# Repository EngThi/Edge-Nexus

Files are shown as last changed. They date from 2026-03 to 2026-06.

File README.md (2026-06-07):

# Edge Nexus: Standalone Industrial Edge Controller

This is a custom industrial carrier board I built for high-noise environments. It uses PC817 optocouplers for isolation and has RS-485/Modbus comms through an SP3485 chip. I managed to get the hardware under $50 by sourcing directly from LCSC and AliExpress.

## Why I built this

Edge Nexus is an industrial controller meant to bridge the gap between standard IoT boards and noisy factory floors. It started as a shield for bigger SBCs, but I decided to make it standalone. It focuses on actual hardware engineering rather than just plugging things into a Linux computer.

I'm a Computer Engineering student and I wanted a solid, protected brain for automation and logging that doesn't cost a fortune like those industrial PLCs you see out there.

## On the board

- ESP32-S3 (WeAct Studio module). It handles the logic, WiFi, and Bluetooth.
- 4-channel input protection using PC817 optocouplers. This stops high-voltage spikes from killing the ESP32.
- SP3485 transceiver for RS-485 / Modbus. This is the standard for industrial PLCs.
- Built-in LM2596 buck converter. You can power the whole thing from a 12-19V laptop brick.
- Two 5V relays to switch actual loads.
- INA219 for power monitoring, SHT41 for temp/humidity, and a DS3231 RTC for keeping time offline.
- MicroSD slot to save logs without needing a cloud connection.
- 40-pin expansion/service header kept for debugging, future wiring, and compatibility experiments.
- Front HMI board with WS2812B status LEDs and a tactile button.

## Design and Making it

### PCB Layout
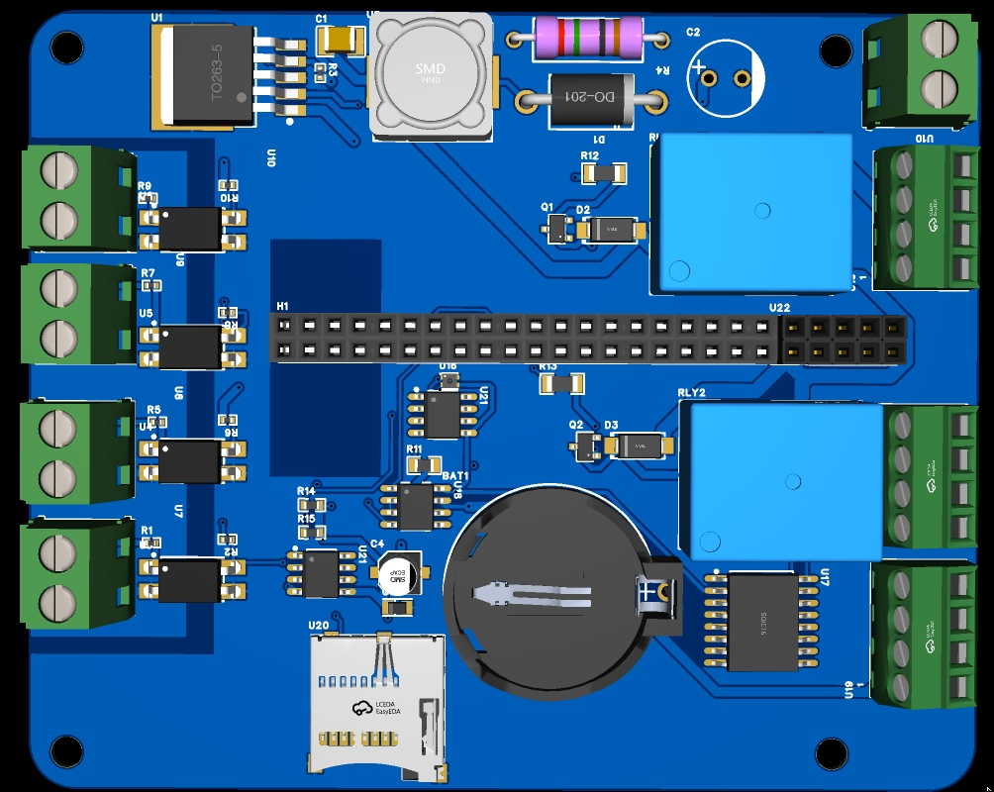
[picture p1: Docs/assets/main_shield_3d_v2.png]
PCB View

*V2 Standalone Controller and the routing details.*

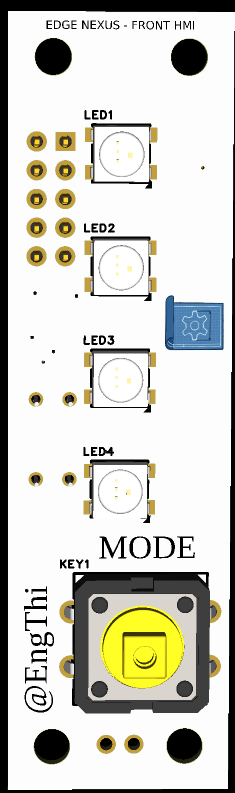
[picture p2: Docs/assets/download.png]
Front HMI View


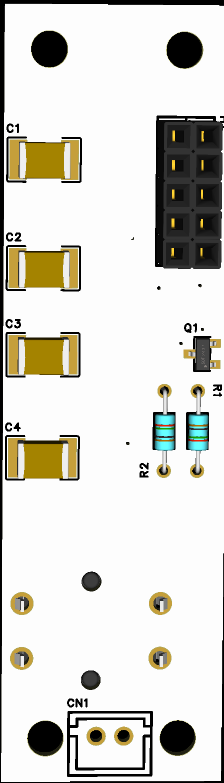
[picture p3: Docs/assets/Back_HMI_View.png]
Back HMI View


### Mechanicals
I designed the enclosure in OnShape with mounting bosses and enough space for the relays and the ESP32.
- [OnShape Public Link](https://cad.onshape.com/documents/763a97ddcd49a121183cadac/w/b6354cba14e3b3f32c74d1b6/e/a910c6222f3a54e8127254ee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)

## How to use it

### Power

The board runs on 12 to 19V DC via a barrel jack. Those small power bricks
that come with set-top boxes and older electronics (the kind everyone has
lying around here in Brazil, usually 12V P4) work fine. Laptop chargers
cover the 19V end. If it outputs somewhere in that range and the connector
fits, it probably works :)

One thing worth knowing: I originally designed this thinking about a
Jetson Nano doing the heavy lifting, model finetuning, industrial
simulations, the kind of workload that needs real compute. After the pivot
to ESP32-S3 that changed. The ESP handles control logic, comms, and
logging really well but it is not going to run ML workloads :/. The 40-pin
header stayed in as an expansion connector if you ever want to attach
something more powerful later.

### DIRTY side vs CLEAN side

The left side of the board is the DIRTY side, that is where your sensors,
actuators, and anything with messy real-world signals connect via screw
terminals. Those signals never touch the ESP directly. The PC817
optocouplers convert them to light pulses and pass only the logic signal
across the isolation barrier to the CLEAN side where the ESP lives. So if
something on the DIRTY side has a spike or does something weird, the ESP
does not care :p

### Flashing the ESP32-S3

I went with MicroPython because iteration is faster, write a `.py`,
upload, test, repeat. But the ESP32-S3 works with C/C++ and even Rust if
you prefer.

**MicroPython:**
Grab the binary for the S3 from the
[official MicroPython page](https://micropython.org/download/ESP32_GENERIC_S3/).
Best IDE for this is Thonny, pick the version, connect the board, select
the COM port and flash the `.bin`. To enter flash mode hold BOOT, tap
EN/RST then release BOOT. Wait for it to finish and you are good :). After
that you write and test `.py` files straight from Thonny's console.

**C/C++ via Arduino IDE, PlatformIO, or ESP-IDF:**
Pick your board (ESP32-S3), pick the COM port, compile and flash. Most of
the time you do not even need to hold BOOT, the toolchain handles it. If
the flash fails or the bar just hangs, hold BOOT when it starts uploading
and release once it moves. That usually fixes it :/

### RS-485 and Modbus

The SP3485 transceiver gives you RS-485, same physical layer most
industrial PLCs use. Modbus RTU runs on top of that so you can talk to
PLCs, VFDs, sensors, basically anything on a factory floor that has a
Modbus register map. Two wires (A and B), twisted pair, multiple devices
on the same bus. The firmware handles DE/RE pin direction switching
automatically so you do not have to manage that manually.

### SD card logging

There is a MicroSD slot that saves telemetry to a simple `.csv`, temperature,
humidity, relay state, timestamps, whatever the firmware is collecting. Right
now it just keeps appending rows to one file :/

Still on the list: better file rotation, separate files per task, checking
card health on boot instead of just assuming it is there. Also been thinking
about pushing data to a cloud dashboard via webhooks, something like
[Blynk](https://www.blynk.io/) which I used in my TCC (that is kind of like
a Capstone Project or Undergraduate Thesis, from my Industrial Automation
technician course here in Brazil). WiFi is already there on the ESP, just
have not wired that part up yet :)

## How I'm assembling it

The PCB is coming bare from JLCPCB. I'm hand-soldering everything myself—optoacopladores, the transceiver, buck converter, and all the headers. I want to verify the isolation gap and continuity manually before I ever turn it on.

## Cost to replicate

This is the price for the parts, not including shipping or taxes.

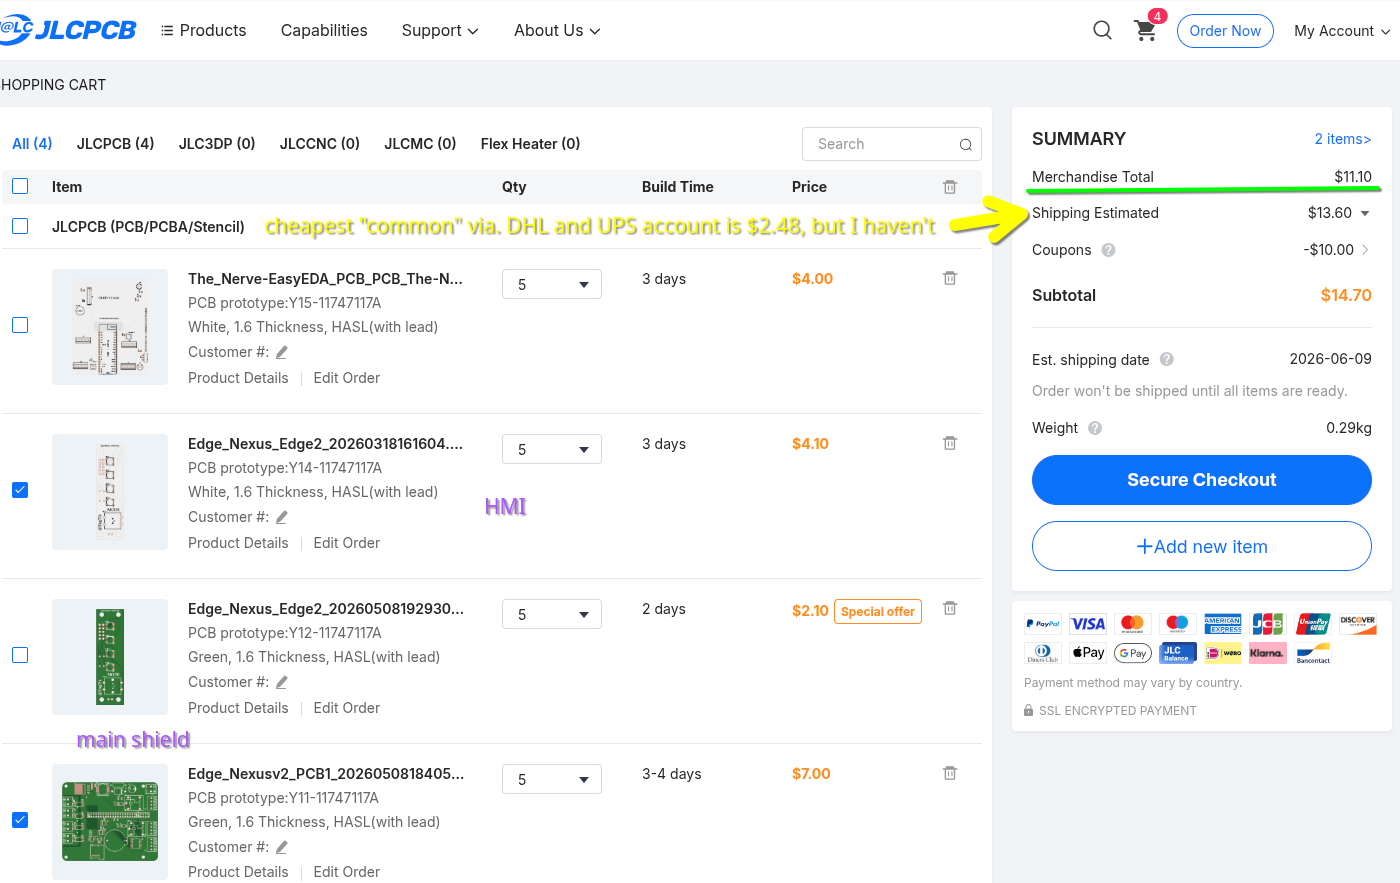
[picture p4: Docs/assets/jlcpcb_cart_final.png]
Final JLCPCB Cart

*Selected JLCPCB PCBs: shield + HMI with logo/sign.*

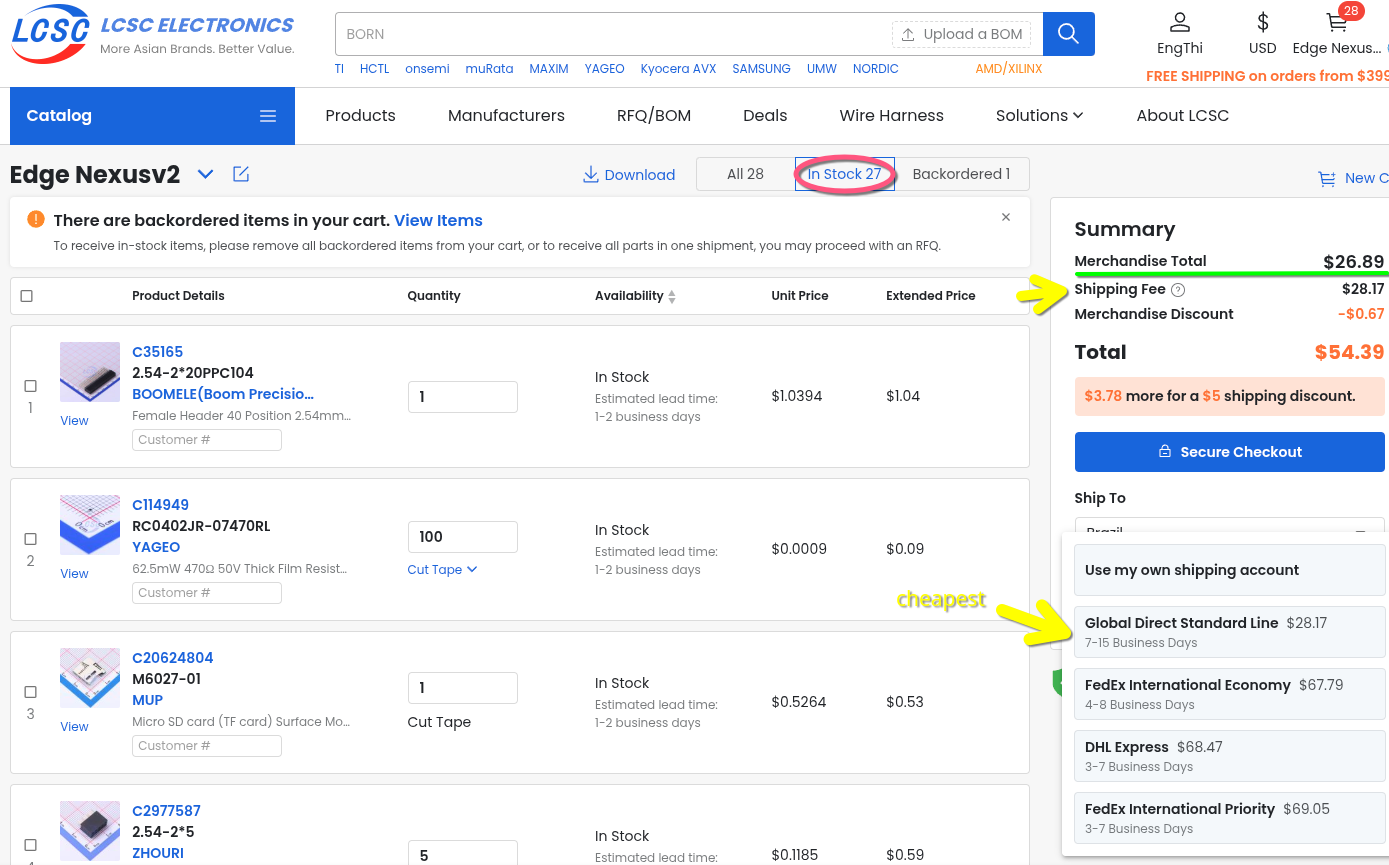
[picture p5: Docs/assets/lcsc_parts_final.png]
Main Shield LCSC Cart

*Main Shield parts from LCSC. This is the cart I submitted with the project.*

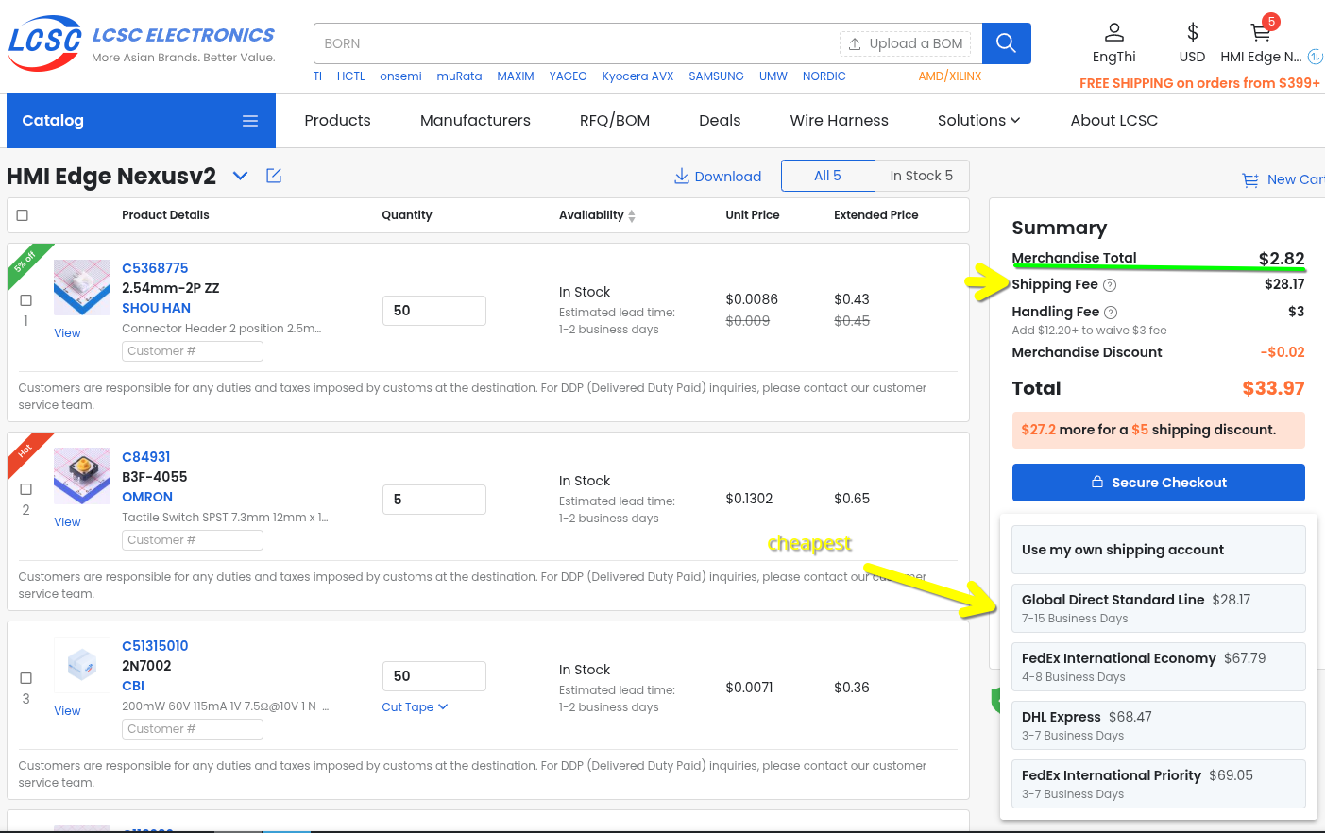
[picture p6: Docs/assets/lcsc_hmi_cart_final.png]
Front HMI LCSC Cart

*Front HMI parts from LCSC.*

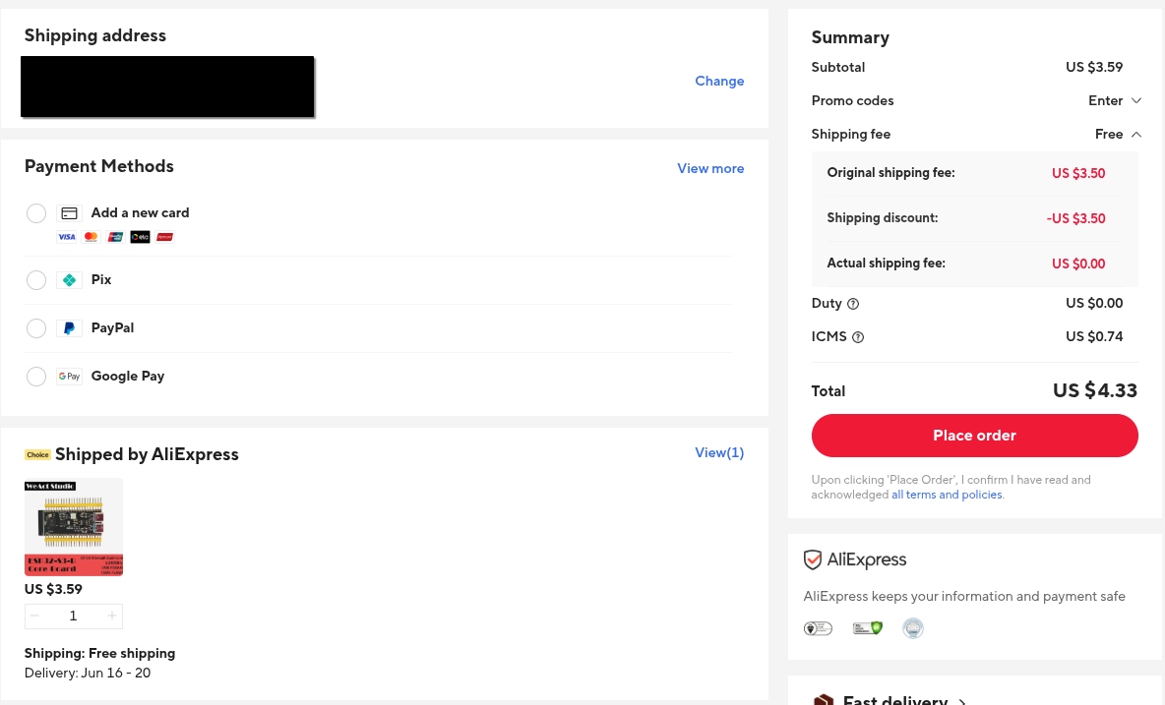
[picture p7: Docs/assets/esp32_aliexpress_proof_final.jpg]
AliExpress Proof

*ESP32-S3 from AliExpress.*

| Item | Qty | From | Price |
| :--- | :--- | :--- | :--- |
| ESP32-S3 WeAct Studio | 1 | AliExpress | $4.33 |
| Main Shield components cart | 1 set | LCSC | $26.89 |
| Front HMI components cart | 1 set | LCSC | $2.82 |
| PCB Manufacturing (Shield + HMI) | 1 set | JLCPCB | $11.10 |
| **Subtotal (Hardware Only)** | | | **$45.14** |

> **Note on cost optimization:** After submitting the form, I noticed that
> combining both LCSC carts into one order drops the total merchandise to
> $29.71 and cuts shipping to a single $28.17 charge instead of two.
> Here's what that looks like:
>
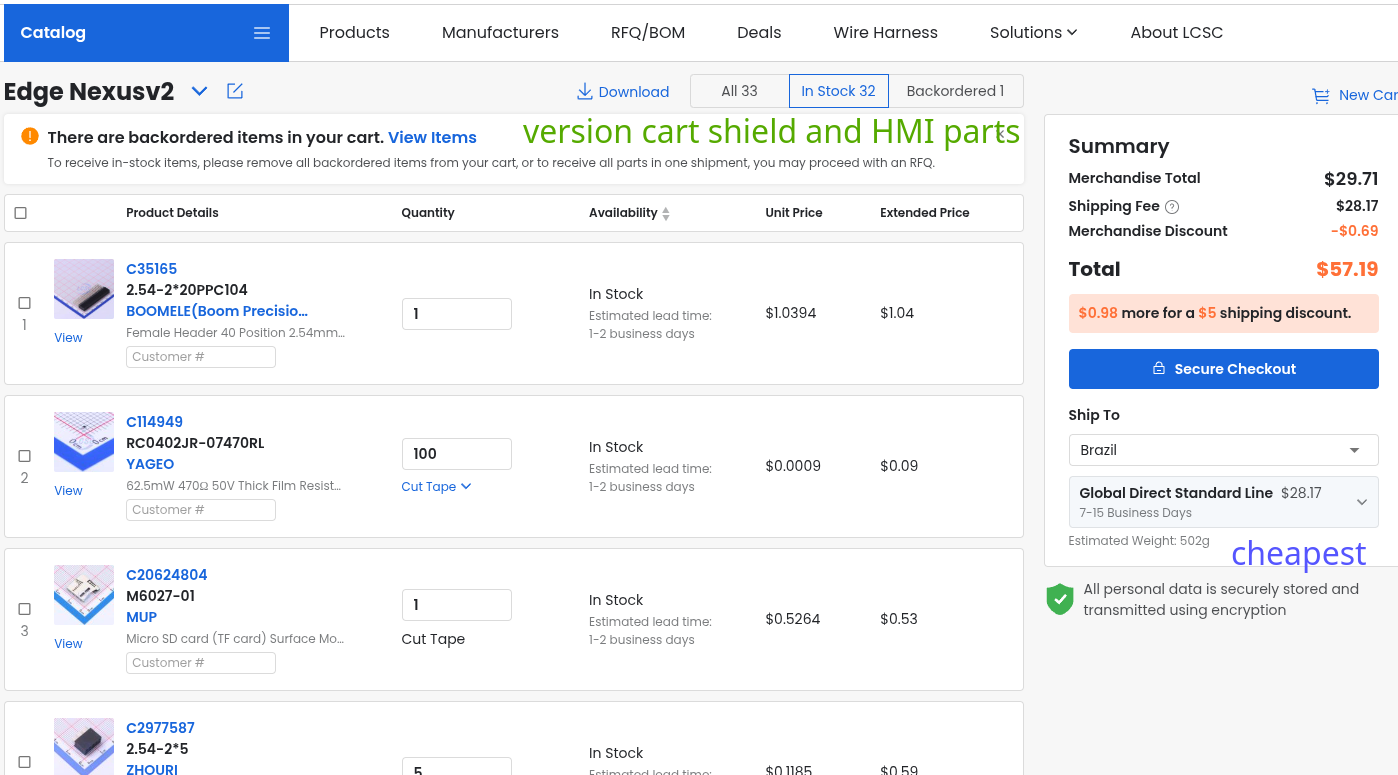
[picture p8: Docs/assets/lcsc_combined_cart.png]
Combined LCSC Cart
> 
> *Shield + HMI parts in one cart — $29.71 merchandise, one shipping charge.*

*(Full details with shipping and taxes in [BLUEPRINT_BUDGET.md](BLUEPRINT_BUDGET.md))*

That total is the real merchandise/cart number before shipping and taxes. It is not a perfect "one resistor costs this much" calculation, because LCSC has MOQ and stock weirdness. Still, it is the number I would rather show because it is what I actually see in the carts.

Note for people in Brazil (São Paulo): If you are around Santa Ifigênia, you can get most of the passives and connectors there for cheap. The ESP32 and LCSC orders usually stay under the tax limit if you're careful.

Check BOM.csv

### Shipping info
I used Global Standard Direct Line for the PCBs, which is the cheapest tracked option to Brazil.

## Folder Structure

```
├── BOM.csv                         # Full parts list
├── JOURNAL.md                      # Engineering logs
├── Hardware/
│   ├── Main_Shield/
│   │   ├── Fabrication/            # Gerbers and BOM
│   │   ├── PCB/                    # EasyEDA files
│   │   └── Schematics/             # PDF Schematic
│   ├── Front_HMI/                  # HMI board files
│   └── 3D_Models/                  # STEP files
├── Docs/                           # Images and renders
└── software/
    └── main.py                     # Firmware
```

---

Developed for Hack Club Blueprint 2026. Designed by @EngThi

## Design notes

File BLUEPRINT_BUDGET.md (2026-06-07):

# Edge Nexus Hardware Budget

This document outlines the hardware costs for Edge Nexus. The budget is split into **Component Base Prices** (the actual cost of the parts) and **Shipping & Taxes** (the fees to get them to Brazil).

## 1. Component Base Prices (Hardware Only)

| Part | Supplier | Price (USD) |
| :--- | :--- | :--- |
| ESP32-S3 WeAct Studio module | AliExpress | $4.33 |
| Main Shield components cart | LCSC | $26.89 |
| Front HMI components cart | LCSC | $2.82 |
| Edge Nexus V2 PCB order (Shield + HMI) | JLCPCB | $11.10 |
| **Subtotal Components** | | **$45.14** |

---

## 2. Shipping & Regional Taxes (Estimated)

| Supplier / Fee Type | Cost (USD) |
| :--- | :--- |
| JLCPCB Shipping | $13.05 |
| LCSC Shipping (Global Direct) | $31.17 |
| AliExpress Taxes (ICMS) | $0.00 (Included in part price) |
| **Subtotal Shipping & Taxes** | **$44.22** |

---

## 3. Final Total

| Total Project Cost | $45.14 (Parts) + $44.22 (Shipping/Taxes) | **$89.36** |
| :--- | :--- | :--- |

## Proof of Costs (Final Carts)
- [AliExpress ESP32 Proof](Docs/assets/esp32_aliexpress_proof_final.jpg)
- [JLCPCB Final Cart](Docs/assets/jlcpcb_cart_final.png)
- [LCSC Main Shield Cart](Docs/assets/lcsc_parts_final.png)
- [LCSC Front HMI Cart](Docs/assets/lcsc_hmi_cart_final.png)
- [LCSC Optimized/Combined Cart](Docs/assets/lcsc_combined_cart.png)

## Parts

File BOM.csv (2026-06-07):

Category | Quantity | Component | Designator | Manufacturer | Part Number | Supplier | Unit Price (USD) | MOQ | Link
Computing | 1 | ESP32-S3 WeAct Studio | U1 | WeAct Studio | ESP32-S3-N16R8 | AliExpress | 4.33 | 1 | https://pt.aliexpress.com/item/1005005592730189.html
Comms | 1 | SP3485 RS-485 Transceiver | U18 | MaxLinear | C8963 | LCSC | 0.45 | 1 | https://www.lcsc.com/product-detail/RS-485-RS-422-Receivers-Transceivers_MaxLinear-Exar-SP3485EN-L-TR_C6767.html
Power | 1 | LM2596S-ADJ Buck Converter | U1 | UMW | C347423 | LCSC | 0.57 | 1 | https://www.lcsc.com/product-detail/DC-DC-Converters_UMW-友台半导体-LM2596S-ADJ-UMW_C347423.html
Isolation | 4 | PC817C Optocoupler | U3-U6 | GOODWORK | C3025164 | LCSC | 0.04 | 20 | https://www.lcsc.com/product-detail/Optoisolators-Transistor-Photovoltaic-Output_GOODWORK-PC817C_C3025164.html
Actuation | 2 | 5V Relay (SRD-05VDC-SL-C) | RLY1-RLY2 | Songle | C35449 | LCSC | 0.42 | 1 | https://www.lcsc.com/product-detail/Relays_Songle-Relay-SRD-05VDC-SL-C_C35449.html
Sensors | 2 | INA219 Current Sensor | U21 | TI | C138706 | LCSC | 0.85 | 1 | https://www.lcsc.com/product-detail/Current-Sensors_Texas-Instruments-INA219AIDR_C138706.html
Sensors | 1 | SHT41A Temp/Hum Sensor | U16 | Sensirion | C7461859 | LCSC | 1.50 | 1 | https://www.lcsc.com/product-detail/Temperature-Humidity-Sensors_Sensirion-AG-SHT41A-BD1B-R2_C7461859.html
Clock | 1 | DS3231 RTC | U17 | Maxim | C722469 | LCSC | 1.20 | 1 | https://www.lcsc.com/product-detail/Real-Time-Clocks-RTC_Maxim-Integrated-DS3231SN_C722469.html
Storage | 1 | MicroSD Slot (SPI) | U20 | MUP | C20624804 | LCSC | 0.15 | 1 | https://www.lcsc.com/product-detail/SD-Card-Connectors_MUP-M6027-01_C20624804.html
Discrete | 2 | S8050 NPN Transistor | Q1-Q2 | CJ | C2146 | LCSC | 0.01 | 50 | https://www.lcsc.com/product-detail/Bipolar-Transistors-BJT_CJ-S8050_C2146.html
Discrete | 1 | 1N5822 Schottky Diode | D1 | LRC | C82806 | LCSC | 0.15 | 5 | https://www.lcsc.com/product-detail/Schottky-Diodes_LRC-1N5822_C82806.html
Discrete | 2 | 1N4007 Diode | D2-D3 | Generic | C727081 | LCSC | 0.02 | 100 | https://www.lcsc.com/product-detail/Diodes-General-Purpose_YONGYUTAI-1N4007_C727081.html
Passives | 1 | 100uH Inductor | U2 | SHOU HAN | C2929505 | LCSC | 0.38 | 5 | https://www.lcsc.com/product-detail/Inductors-SMD_SHOU-HAN-CYH127-100UH_C2929505.html
Passives | 1 | 220uF Capacitor | C1 | SAMSUNG | C400951 | LCSC | 0.91 | 1 | https://www.lcsc.com/product-detail/Multilayer-Ceramic-Capacitors-MLCC-SMD-SMT_SAMSUNG-CL32A227MQVNNNE_C400951.html
Passives | 1 | 100uF Capacitor (35V) | C2 | Econd | C49304899 | LCSC | 0.10 | 10 | https://www.lcsc.com/product-detail/Electrolytic-Capacitors-Leaded_Econd-100uF35V8x11GF_C49304899.html
Passives | 1 | 10uF Capacitor | C3 | CEC | C2976905 | LCSC | 0.05 | 10 | https://www.lcsc.com/product-detail/Tantalum-Capacitors_CEC-CA45A-P-6-3V-10UF-K_C2976905.html
Passives | 1 | 100nF Capacitor | C4 | HUAWEI | C271438 | LCSC | 0.02 | 100 | https://www.lcsc.com/product-detail/Aluminum-Electrolytic-Capacitors-SMD_HUAWEI-VT1H0R1MB054000CE0_C271438.html
Passives | 4 | 470Ω Resistor 0402 | R1,R5,R7,R9 | YAGEO | C114949 | LCSC | 0.001 | 100 | https://www.lcsc.com/product-detail/Chip-Resistor-Surface-Mount_YAGEO-RC0402JR-07470RL_C114949.html
Passives | 5 | 10kΩ Resistor 0402 | R2,R3,R6,R8,R10 | EVER OHMS | C149898 | LCSC | 0.02 | 50 | https://www.lcsc.com/product-detail/Chip-Resistor-Surface-Mount_EVER-OHMS-TR0402D10K0Q1025Z_C149898.html
Passives | 2 | 4.7kΩ Resistor 0603 | R14-R15 | UNI-ROYAL | C23162 | LCSC | 0.01 | 100 | https://www.lcsc.com/product-detail/Chip-Resistor-Surface-Mount_UNI-ROYAL-0603WAF4701T5E_C23162.html
Passives | 2 | 1kΩ Resistor 1206 | R12-R13 | UNI-ROYAL | C4410 | LCSC | 0.01 | 100 | https://www.lcsc.com/product-detail/Chip-Resistor-Surface-Mount_UNI-ROYAL-1206W4F1001T5E_C4410.html
Passives | 1 | 120Ω Resistor 0805 | R11 | Generic | C384167 | LCSC | 0.01 | 100 | https://www.lcsc.com/product-detail/Chip-Resistor-Surface-Mount_UNI-ROYAL-WR08X121JTL_C384167.html
Passives | 1 | 3.3kΩ Resistor TH | R4 | Huaxing | C714109 | LCSC | 0.03 | 20 | https://www.lcsc.com/product-detail/Through-Hole-Resistors_华星机电-MF1W-3.3K-1-T_C714109.html
Connectors | 1 | 40-pin Female Header (PC104) | H1 | BOOMELE | C35165 | LCSC | 1.03 | 1 | https://www.lcsc.com/product-detail/Female-Headers_BOOMELE-C35165_C35165.html
Connectors | 1 | CR2032 Battery Holder | BAT1 | Generic | C9900018737 | LCSC | 0.25 | 1 | https://www.lcsc.com/product-detail/Battery-Holders_CR2032-2-1_C9900018737.html
Connectors | 4 | KF128-5.0-2P Screw Terminal | J2-J5 | KEFA | C474950 | LCSC | 0.18 | 5 | https://www.lcsc.com/product-detail/Screw-Terminal-Blocks_KEFA-KF128-5.0-2P_C474950.html
Connectors | 3 | 4-pin Screw Terminal (3.5mm) | U19 | MAX | C5349545 | LCSC | 0.30 | 1 | https://www.lcsc.com/product-detail/Screw-Terminal-Blocks_MAX-MX127S-3-5-04P-GN01-CU-Y-A_C5349545.html
Connectors | 1 | 2x5 pin Header | U22 | ZHOURI | C2977587 | LCSC | 0.15 | 1 | https://www.lcsc.com/product-detail/Female-Headers_ZHOURI-2-54-2-5_C2977587.html
Passives | 4 | 100nF Film Capacitor | C1-C4 | WIMA | C19855121 | LCSC | 0.136 | 1 | https://www.lcsc.com/product-detail/Film-Capacitors_WIMA-SMDTC03100KB00KP00_C19855121.html
Connectors | 1 | 2.54mm-2P ZZ Header | CN1 | SHOU HAN | C5368775 | LCSC | 0.0013 | 1 | https://www.lcsc.com/product-detail/Wire-To-Board-Connector_SHOU-HAN-2-54mm-2P-ZZ_C5368775.html
Connectors | 1 | 2x5 pin Female Header | H1 | BOOMELE | C30419 | LCSC | 0.0097 | 1 | https://www.lcsc.com/product-detail/Female-Headers_BOOMELE-HDR2-54-F-LI-2X5P_C30419.html
Switches | 1 | Tactile Switch B3F-4055 | KEY1 | OMRON | C84931 | LCSC | 0.0207 | 1 | https://www.lcsc.com/product-detail/Tactile-Switches_OMRON-B3F-4055_C84931.html
Optoelectronics | 4 | WS2812B-V5 RGB LED | LED1-LED4 | worldsemi | C2846931 | LCSC | 0.143 | 1 | https://www.lcsc.com/product-detail/RGB-LEDs-Built-in-IC_worldsemi-WS2812B-V5_C2846931.html
Discrete | 1 | 2N7002 MOSFET | Q1 | CBI | C51315010 | LCSC | 0.0011 | 1 | https://www.lcsc.com/product-detail/MOSFETs_CBI-2N7002_C51315010.html
Resistors | 2 | 10kΩ TH Resistor | R1-R2 | CCO | C119202 | LCSC | 0.0016 | 1 | https://www.lcsc.com/product-detail/Through-Hole-Resistors_CCO-MF1-8W-10K-1-T_C119202.html
PCB | 1 | Edge Nexus V2 PCB (Shield) | Main | JLCPCB | Custom | JLCPCB | 7.00 | 5 | https://jlcpcb.com
PCB | 1 | Edge Nexus Front HMI PCB (Logo/Sign) | HMI | JLCPCB | Custom | JLCPCB | 4.10 | 5 | https://jlcpcb.com

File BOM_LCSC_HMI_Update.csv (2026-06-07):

Index | LCSC# | MPN | Manufacturer | Package | Customer # | Description | RoHS | Quantity | MOQ | Multiple | Unit Price($) | Extended Price($) | Product Link
1 | C5368775 | 2.54mm-2P ZZ | SHOU HAN | Through Hole,P=2.5mm |  | Connector Header 2 position 2.5mm Pitch 3A Through Hole -25℃~+85℃ | yes | 50 | 50 | 50 | 0.0086 | 0.43 | https://www.lcsc.com/product-detail/C5368775.html
2 | C84931 | B3F-4055 | OMRON | Through Hole-4P,12x12mm |  | Tactile Switch SPST 7.3mm 12mm x 12mm Through Hole | yes | 5 | 5 | 5 | 0.1302 | 0.65 | https://www.lcsc.com/product-detail/C84931.html
3 | C51315010 | 2N7002 | CBI | SOT-23 |  | 200mW 60V 115mA 1V 7.5Ω@10V 1 N-channel N-Channel SOT-23 Single FETs, MOSFETs RoHS | yes | 50 | 50 | 50 | 0.0071 | 0.36 | https://www.lcsc.com/product-detail/C51315010.html
4 | C119202 | MF1/8W-10KΩ±1% T | CCO(Chian Chia Elec) | Through Hole,D1.8xL3.2mm |  | 10kΩ 125mW 150V Metal Film Resistor ±100ppm/℃ ±1% Through Hole,D1.8xL3.2mm Through Hole Resistors RoHS | yes | 50 | 50 | 50 | 0.0104 | 0.52 | https://www.lcsc.com/product-detail/C119202.html
5 | C49678 | CC0805KRX7R9BB104 | YAGEO | 0805 |  | 100nF ±10% 50V Ceramic Capacitor X7R 0805 | yes | 100 | 100 | 100 | 0.0084 | 0.84 | https://www.lcsc.com/product-detail/C49678.html

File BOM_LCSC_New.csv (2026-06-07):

Index | LCSC# | MPN | Manufacturer | Package | Customer # | Description | RoHS | Quantity | MOQ | Multiple | Unit Price($) | Extended Price($) | Product Link
1 | C35165 | 2.54-2*20PPC104 | BOOMELE(Boom Precision Elec) | Through Hole,P=2.54mm |  | Female Header 40 Position 2.54mm Pitch Dual Row Through Hole | yes | 1 | 1 | 1 | 1.0394 | 1.04 | https://www.lcsc.com/product-detail/C35165.html
2 | C7461859 | SHT41A-BD1B-R2 | Sensirion | - |  | - | - | 1 | 1 | 1 | 2.2096 | 2.21 | -
3 | C114949 | RC0402JR-07470RL | YAGEO | 0402 |  | 62.5mW 470Ω 50V Thick Film Resistor ±100ppm/℃ ±5% 0402 Chip Resistor - Surface Mount RoHS | yes | 100 | 100 | 100 | 0.0009 | 0.09 | https://www.lcsc.com/product-detail/C114949.html
4 | C20624804 | M6027-01 | MUP | SMD |  | Micro SD card (TF card) Surface Mount | yes | 1 | 1 | 1 | 0.5264 | 0.53 | https://www.lcsc.com/product-detail/C20624804.html
5 | C2977587 | 2.54-2*5 | ZHOURI | Through Hole,P=2.54mm |  | Female Header 10 Position 2.54mm Pitch Dual Row Through Hole -40℃~+105℃ | yes | 5 | 5 | 5 | 0.1185 | 0.59 | https://www.lcsc.com/product-detail/C2977587.html
6 | C49304899 | 100uF35V8x11GF | Econd | Through Hole,D8xL11mm |  | ±20% 35V 100uF 170mΩ Through Hole,D8xL11mm Aluminum Electrolytic Capacitors RoHS | yes | 20 | 20 | 20 | 0.0281 | 0.56 | https://www.lcsc.com/product-detail/C49304899.html
7 | C5365915 | KH-CR2032-2-1 | kinghelm | Through Hole |  | Battery base Tin Brass -55℃~+105℃ CR2032 Through Hole Blade Type Power Connector Assemblies RoHS | yes | 5 | 5 | 5 | 0.1366 | 0.68 | https://www.lcsc.com/product-detail/C5365915.html
8 | C722469 | DS3231SN# | MAXIM | SOIC-16-300mil |  | Built-in Yes SOIC-16-300mil Real Time Clocks RoHS | yes | 1 | 1 | 1 | 6.0330 | 6.03 | https://www.lcsc.com/product-detail/C722469.html
9 | C727081 | 1N4007 | TWGMC | SMA(DO-214AC) |  | Diode Independent 1kV 1A Surface Mount SMA(DO-214AC) | yes | 50 | 50 | 50 | 0.0091 | 0.46 | https://www.lcsc.com/product-detail/C727081.html
10 | C35449 | SRD-05VDC-SL-C | Songle Relay | Through Hole,19.2x15.6mm |  | Power Relay 1 Form C: 1C (SPDT-CO) 5V Coil Through Hole,15.6x19.2mm | yes | 2 | 1 | 1 | 0.4880 | 0.98 | https://www.lcsc.com/product-detail/C35449.html
11 | C163961 | WR08X121JTL | Walsin | 0805 |  | 125mW 120Ω 150V Thick Film Resistor ±100ppm/℃ ±5% 0805 Chip Resistor - Surface Mount RoHS | yes | 100 | 100 | 100 | 0.0024 | 0.24 | https://www.lcsc.com/product-detail/C163961.html
12 | C8963 | SP3485EN-L/TR | MaxLinear | SOIC-8 |  | 3.3V Transceiver 10Mbps 32 Half-Duplex SOIC-8 Drivers, Receivers, Transceivers RoHS | yes | 2 | 2 | 2 | 0.3085 | 0.62 | https://www.lcsc.com/product-detail/C8963.html
13 | C271438 | VT1H0R1MB054000CE0 | huawei group | SMD,D4xL5.4mm |  | 0.1uF ±20% 50V Aluminum Electrolytic Capacitors 1000hrs@105℃ | yes | 20 | 20 | 20 | 0.0406 | 0.81 | https://www.lcsc.com/product-detail/C271438.html
14 | C2976905 | CA45A-P-6.3V-10UF-K | XY(Zhenhua XinYun) | SMD,1.25x2mm |  | 10uF ±10% 6.3V Tantalum Capacitors SMD,1.25x2mm | yes | 5 | 5 | 5 | 0.1137 | 0.57 | https://www.lcsc.com/product-detail/C2976905.html
15 | C2146 | S8050 J3Y(RANGE:200-350) | JSCJ | SOT-23 |  | Bipolar (BJT) Transistor NPN 25V 0.5A 150MHz 0.3W Surface Mount SOT-23 | yes | 50 | 50 | 50 | 0.0133 | 0.67 | https://www.lcsc.com/product-detail/C2146.html
16 | C4410 | 1206W4F1001T5E | UNI-ROYAL | 1206 |  | 1kΩ ±1% 250mW 1206 Thick Film Resistor | yes | 100 | 100 | 100 | 0.0045 | 0.45 | https://www.lcsc.com/product-detail/C4410.html
17 | C138706 | INA219AIDR | TI | SOIC-8 |  | 0V~26V 10uV 20nA 1 SOIC-8 Current Regulation/Management RoHS | yes | 2 | 1 | 1 | 0.9815 | 1.96 | https://www.lcsc.com/product-detail/C138706.html
18 | C474950 | KF128-5.0-2P | Cixi Kefa Elec | Through Hole,P=5mm |  | 2 Position Wire to Board Terminal Block Through Hole 5mm | yes | 5 | 5 | 5 | 0.1838 | 0.92 | https://www.lcsc.com/product-detail/C474950.html
19 | C347423 | LM2596S-ADJ(UMW) | UMW | TO-263-5 |  | 150kHz Step-down type Adjustable 1.2V~37V 3A TO-263-5 Voltage Regulators - DC DC Switching Regulators RoHS | yes | 1 | 1 | 1 | 0.5504 | 0.55 | https://www.lcsc.com/product-detail/C347423.html
20 | C3025164 | PC817C | GOODWORK | SMD-4P |  | Phototransistor Output 5kVrms 1 Channel SMD-4P | yes | 20 | 20 | 20 | 0.0391 | 0.78 | https://www.lcsc.com/product-detail/C3025164.html
21 | C400951 | CL32A227MQVNNNE | Samsung Electro-Mechanics | 1210 |  | 220uF ±20% 6.3V Ceramic Capacitor X5R 1210 | yes | 1 | 1 | 1 | 1.0069 | 1.01 | https://www.lcsc.com/product-detail/C400951.html
22 | C2929505 | CYH127-100UH | SHOU HAN | SMD,12.3x12.3mm |  | 1.7A 100uH ±20% 220mΩ SMD,12.3x12.3mm Fixed Inductors RoHS | yes | 5 | 5 | 5 | 0.3858 | 1.93 | https://www.lcsc.com/product-detail/C2929505.html
23 | C149898 | TR0402D10K0Q1025Z | EVER OHMS | 0402 |  | 63mW 10kΩ 25V Thin Film Resistor ±0.5% ±25ppm/℃ 0402 Chip Resistor - Surface Mount RoHS | yes | 50 | 50 | 50 | 0.0173 | 0.87 | https://www.lcsc.com/product-detail/C149898.html
24 | C5349545 | MX127S-3.5-04P-GN01-Cu-Y-A | MAX | Through Hole,P=3.5mm |  | 4 Position Wire to Board Terminal Block Through Hole 3.5mm | yes | 3 | 1 | 1 | 0.4456 | 1.34 | https://www.lcsc.com/product-detail/C5349545.html
25 | C99782 | RC0603FR-074K7L | YAGEO | 0603 |  | 100mW 4.7kΩ 75V Thick Film Resistor ±100ppm/℃ ±1% 0603 Chip Resistor - Surface Mount RoHS | yes | 100 | 100 | 100 | 0.0018 | 0.18 | https://www.lcsc.com/product-detail/C99782.html
26 | C119335 | MF1/4W-3.3KΩ±1% T | CCO(Chian Chia Elec) | Through Hole,D2.3xL6.5mm |  | 3.3kΩ 250mW 250V Metal Film Resistor ±100ppm/℃ ±1% Through Hole,D2.3xL6.5mm Through Hole Resistors RoHS | yes | 50 | 50 | 50 | 0.0109 | 0.55 | https://www.lcsc.com/product-detail/C119335.html
27 | C52023798 | 1N5822 | HANGYU MICROELECTRONICS | DO-201AD |  | 40V 1 Independent 525mV@3A 3A DO-201AD Single Diodes RoHS | yes | 10 | 10 | 10 | 0.0569 | 0.57 | https://www.lcsc.com/product-detail/C52023798.html
28 | C54823945 | SHT40-AD1F-R2(TOKMAS) | Tokmas | DFN-4(1.5x1.5) |  | DFN-4(1.5x1.5) Humidity, Moisture Sensors RoHS | yes | 1 | 1 | 1 | 1.2362 | 1.24 | https://www.lcsc.com/product-detail/C54823945.html

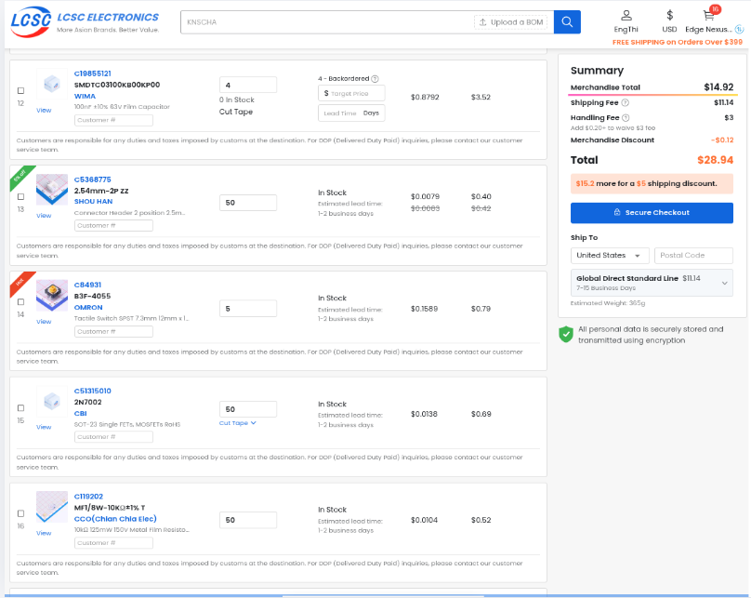
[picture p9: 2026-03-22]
Docs/assets/parts3.png

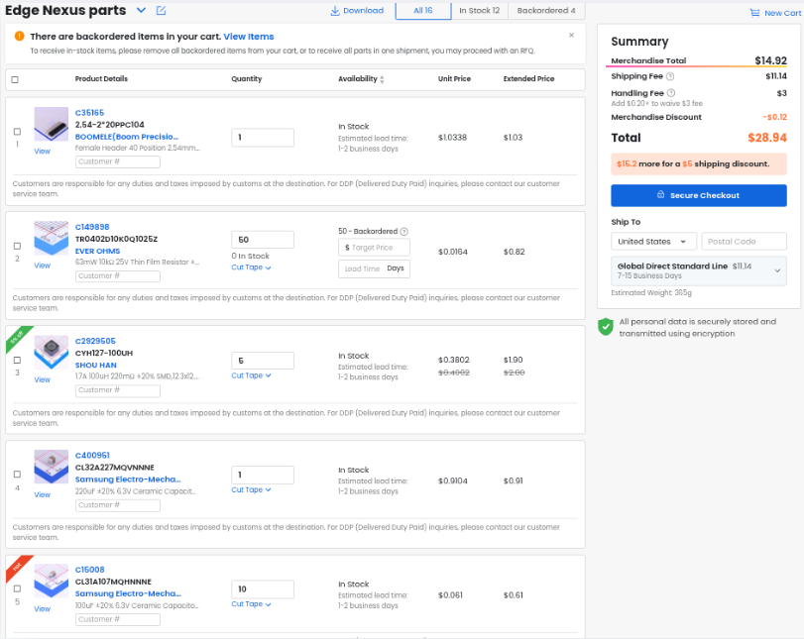
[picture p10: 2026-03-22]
Docs/assets/parts1.png

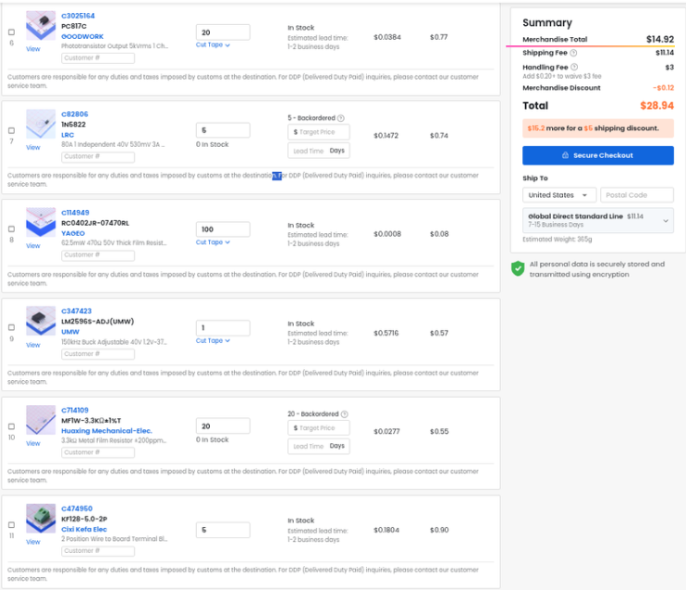
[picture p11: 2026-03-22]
Docs/assets/parts2.png

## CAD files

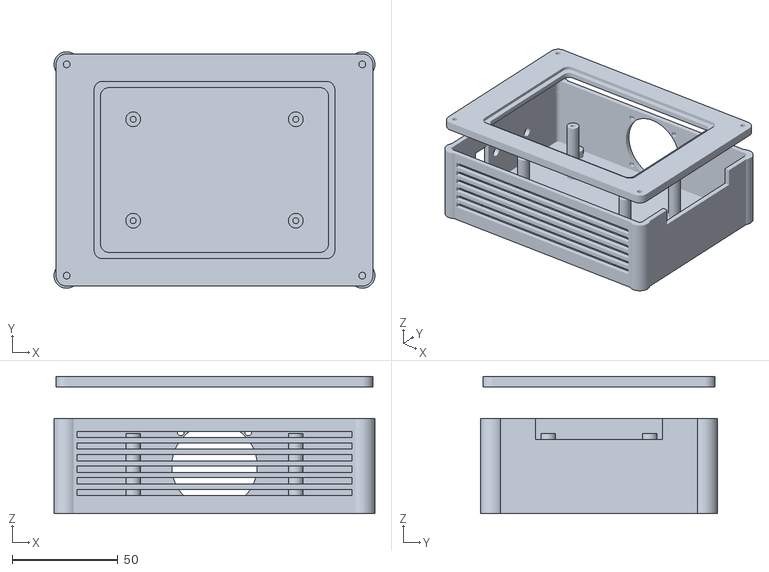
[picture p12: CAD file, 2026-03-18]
Hardware/3D_Models/Edge_Nexus_Enclosure_Case.stl
152.0 x 112.0 x 65.0

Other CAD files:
Hardware/3D_Models/Edge_Nexus_HMI_3D_Model.step

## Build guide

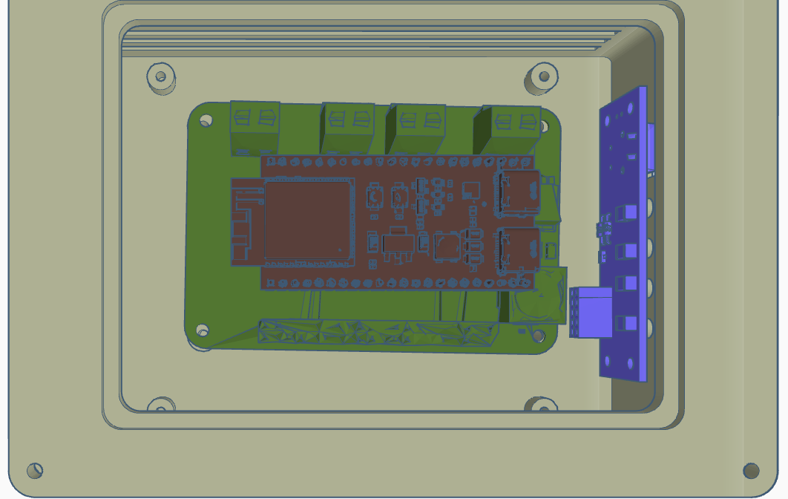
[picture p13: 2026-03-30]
Docs/assets/assembly_view.png

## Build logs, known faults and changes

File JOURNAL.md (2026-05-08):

# Edge Nexus Build Logs

_Industrial isolation and standalone control._

Approximate time: **~85h**

Edge Nexus started because I wanted something closer to real industrial hardware, not only another dev board plugged into jumper wires. The main idea was isolation first: if this is going near noisy sensors, relays, long wires, or anything factory-like, the `ESP32` side cannot be directly exposed to everything.

I did not want this to feel like "I connected a module and called it a controller". I wanted the board to have some real protection and a reason to exist :D

---

### Feb 27

_Time spent: ~5h_

I started with the schematic and the first PCB layout in `EasyEDA`.

The first real block was the input side. I designed a 4-channel isolation front-end using `PC817` optocouplers and screw terminals. Each channel got a `470 ohm` resistor on the sensor/input side for 5V signals and `10k` pull-ups on the 3.3V side.

This was the part where the board stopped being "just ESP32 stuff" and started looking like something that could survive a rougher environment. At least in theory. Hardware always has that little fear of "ok but will this actually work when powered?" :|

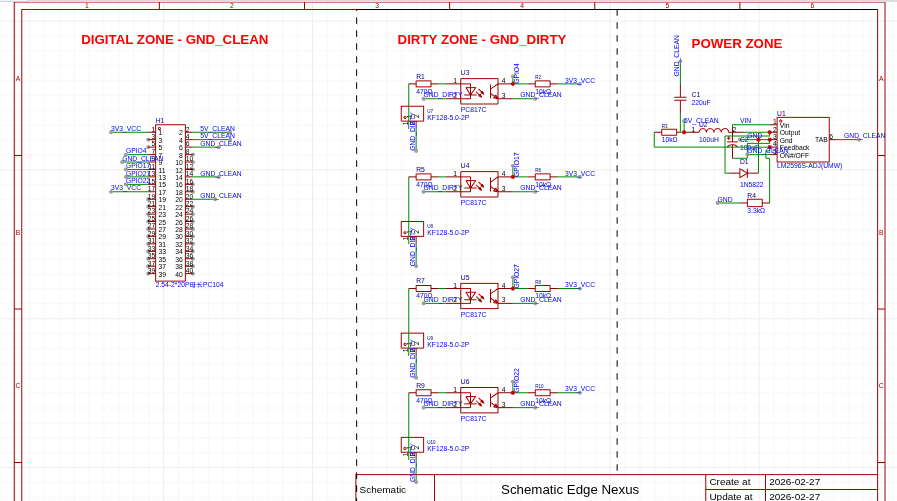
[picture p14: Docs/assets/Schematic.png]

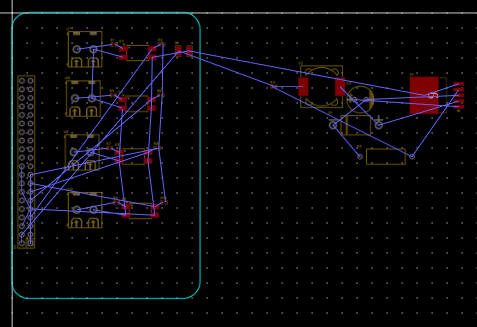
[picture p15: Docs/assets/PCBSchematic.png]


I also added the 40-pin header strategy here. It is not the whole point of V2 anymore, but it stayed useful as an expansion/service connector and for keeping the board flexible.

---

### Feb 28 - Mar 2

_Time spent: ~13h_

Routing was annoying from the start :/

The `EasyEDA` auto-router completely ignored the point of galvanic isolation. It tried to route traces through the isolation barrier, which basically destroys the reason for using optocouplers. So I deleted that and routed manually.

The `LM2596` buck area also needed attention because I wanted it to handle real current. I used wider traces around the power section and kept checking the copper pours because they kept refusing to connect in the way I expected.

At one point I had more than 70 `DRC` errors. Some were real problems, some were clearance settings fighting me. I reset the clearance rules to `0.254mm`, routed ground more carefully, and got it down to 0 errors. That felt very good, because before that it looked like the board was just screaming at me.

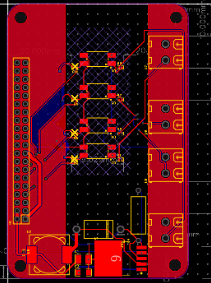
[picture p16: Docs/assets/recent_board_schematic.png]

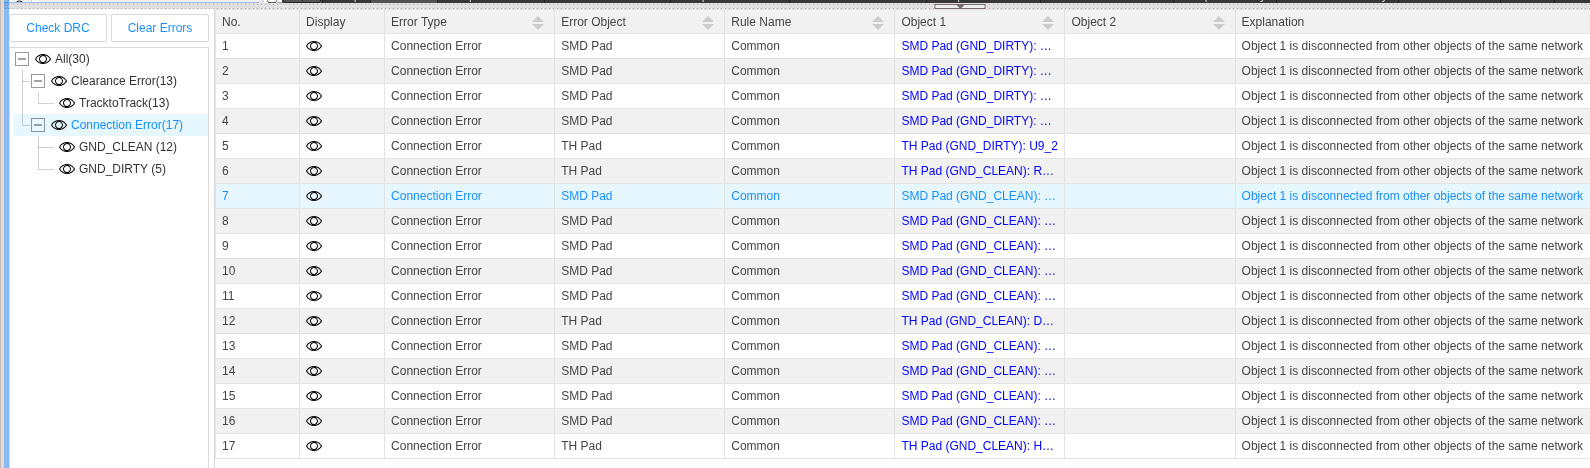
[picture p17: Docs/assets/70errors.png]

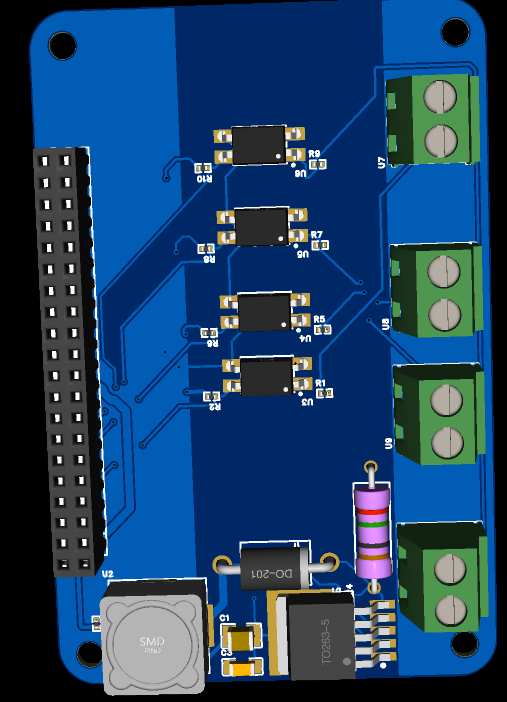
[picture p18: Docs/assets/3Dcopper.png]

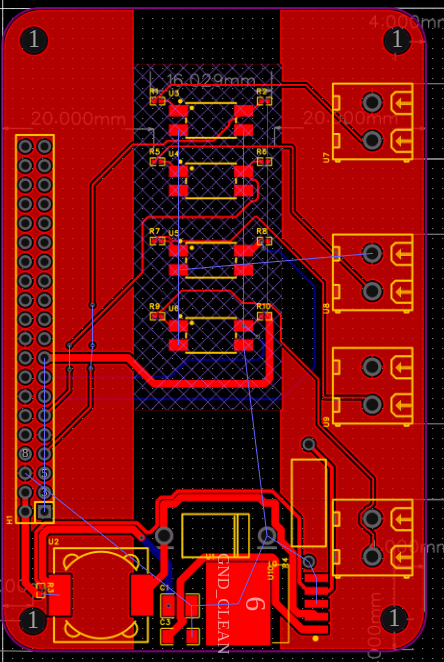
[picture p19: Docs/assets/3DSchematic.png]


This was not glamorous. It was mostly moving traces, checking, getting annoyed, and moving them again :/

---

### Mar 3 - Mar 6

_Time spent: ~8h_

I imported the PCB `.STEP` into `OnShape` and started designing the chassis.

I wanted it to feel more like an industrial controller than a random exposed PCB. That meant thinking about where the board sits, where screws go, how the case closes, and whether the mounting holes actually line up. They did not line up perfectly at first, so I had to go back to `EasyEDA`, fix holes, export again, and check the CAD again.

This back-and-forth is boring but it is also the kind of thing that makes the final project not look improvised.

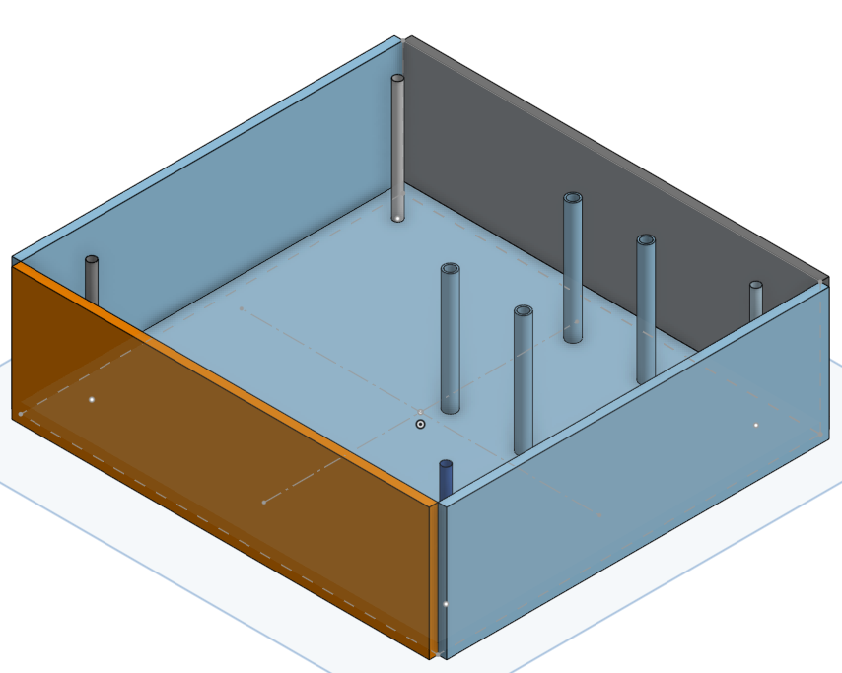
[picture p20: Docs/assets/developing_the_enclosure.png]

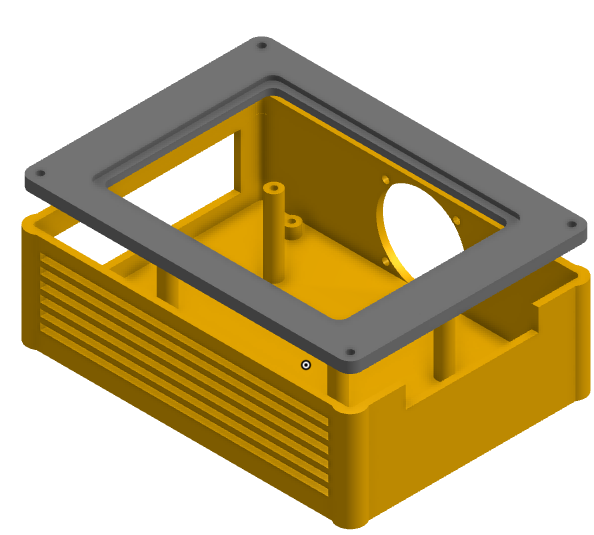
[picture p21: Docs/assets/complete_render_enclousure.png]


Small mechanical mistakes are very easy to ignore in 2D and very obvious in 3D. Painful but useful :/

---

### Mar 7 - Mar 9

_Time spent: ~11h_

I worked on the front HMI board. It is a small `70x20mm` board for the front panel with `WS2812B` LEDs and a simple interface idea.

The traces were not complicated like the main board, but I still had to be careful with power. The `5V` and `GND` lines for LEDs need to be more serious than tiny signal traces.

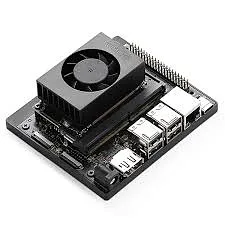
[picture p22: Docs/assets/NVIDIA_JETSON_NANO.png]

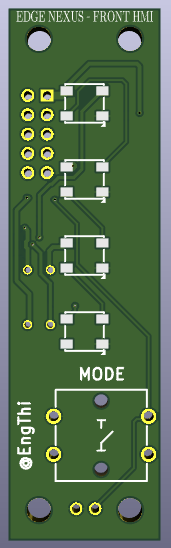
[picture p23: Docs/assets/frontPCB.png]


At this stage the project was still connected to the idea of using a Jetson/Orange Pi style SBC. I thought the shield plus HMI plus enclosure would be enough.

Looking back, this was the "almost cool but not really the right project yet" phase.

---

### Mar 10 - Mar 17

_Time spent: ~20h_

I integrated the first version into the enclosure. The isolation board sat above the SBC area, and the HMI board mounted behind the front panel with `M3` bolts.

I changed the front from one big display/window cutout to individual LED/button cutouts. It looked cleaner and more like a piece of equipment instead of a box with a random hole.

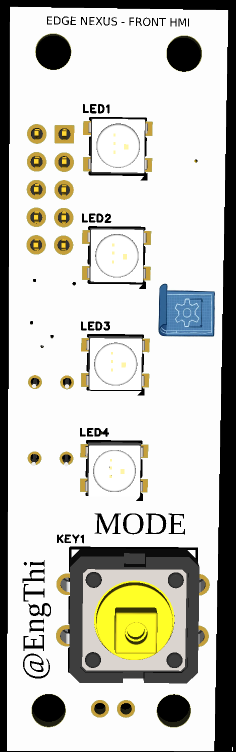
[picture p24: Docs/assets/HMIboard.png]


I also wrote a small `Jetson.GPIO` LED test script and cleaned up the repo. At this point I thought V1 was basically done.

_It was not done._

---

### Mar 18 - Mar 27

_Time spent: ~15h_

The review changed the project a lot.

The feedback was basically that Hack Club funds custom hardware, not a $150 NVIDIA computer with my shield sitting on top. That hurt a bit, but it was fair. V1 still depended too much on a prebuilt SBC.

I had that moment of "bruh... yeah, they are right" :(

So I pivoted Edge Nexus into a standalone controller around an `ESP32-S3 WeAct Studio` module. The 40-pin header stayed in the design as an expansion/service connector, but the board no longer depends on a Jetson/Orange Pi to be the brain.

What changed:

- Added `SP3485` for `RS-485`.
- Added 2 relays for switching loads.
- Added `INA219` power monitoring.
- Added `SHT41` temperature/humidity sensing.
- Added `DS3231` RTC for offline timekeeping.
- Added MicroSD logging.
- Kept the `PC817` isolation stage.

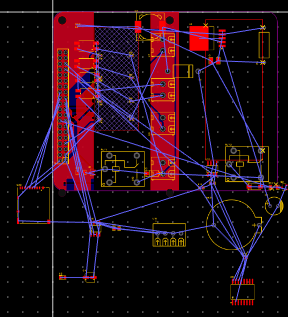
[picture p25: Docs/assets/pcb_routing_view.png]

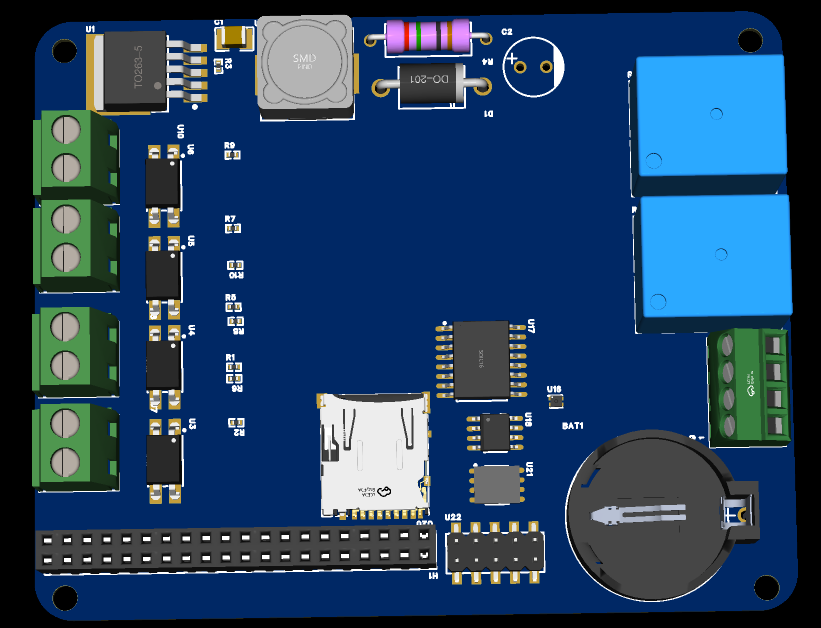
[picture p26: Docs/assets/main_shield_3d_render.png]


The component count got much bigger, but I still wanted the board around `100x80mm`. This was the most "ok, now this is actually hardware engineering" part.

---

### Mar 28 - Mar 31

_Time spent: ~10h_

Fitting everything was a puzzle.

One rookie mistake: I had screw terminals too far inside the board at one point. That looks fine in PCB view until you imagine using a screwdriver and the `ESP32` module is in the way. So I moved connectors toward the edges. Very obvious after noticing it, very annoying before noticing it.

I also used the vertical space more aggressively. The `CR2032` holder sits under the raised ESP32 module area, which saves board space without making the board larger.

For isolation, I kept a `1.5mm` air gap between the noisy/input side and the logic side. I also split the ground thinking into cleaner and dirtier areas so the isolation section still makes sense physically.

_Small board, too many parts, lots of moving things around._ :|

---

### Apr 1

_Time spent: ~2h_

Final cleanup day. Or at least "please be final" day.

I fixed a collision between the MicroSD slot and the ESP32 in the 3D view, updated silkscreen labels, generated the Gerbers/BOM, and adjusted the enclosure for the new V2 board.

At that point, the hardware cost was:

- AliExpress ESP32-S3: $6.66
- LCSC components cart: $43.43
- JLCPCB bare PCB: $6.10
- **Total: $56.19**

I am not using PCBA, so this means hand soldering the board. Not relaxing, but it keeps the project under the budget and makes the build more real. Also a little scary, because small parts do not care that this is my project :/

Timelapses:

- [New parts and searching](https://lapse.hackclub.com/timelapse/lmfT6dZKEx6h)
- [Working to submit](https://lapse.hackclub.com/timelapse/3QgjKu2FWrUs)
- [Making the pivot](https://lapse.hackclub.com/timelapse/ZSAejujQKgtY)

Edge Nexus V2 is ready enough to submit. I hope this one makes the point better :)

###### May 8 — Final Cart Fix, Because I Did Forget Something
*Time spent: ~1h*
Updated the final carts before submission and then had the annoying reviewer moment: "maybe something is missing". It was. I had the Main Shield cart clean, but the Front HMI had its own little BOM with the LEDs, button, MOSFET, header and caps, and I had not reflected that properly in the root `BOM.csv`.

So now the budget is honest: ESP32 from AliExpress is $6.87, Main Shield LCSC cart is $26.52, Front HMI LCSC cart is $5.53, and the selected JLCPCB boards are $11.10 because I picked the HMI with logo/sign plus the shield. Final merchandise total is **$50.02** before shipping/taxes. Still under $60, but yeah, not the fake-clean $42.49 anymore :/

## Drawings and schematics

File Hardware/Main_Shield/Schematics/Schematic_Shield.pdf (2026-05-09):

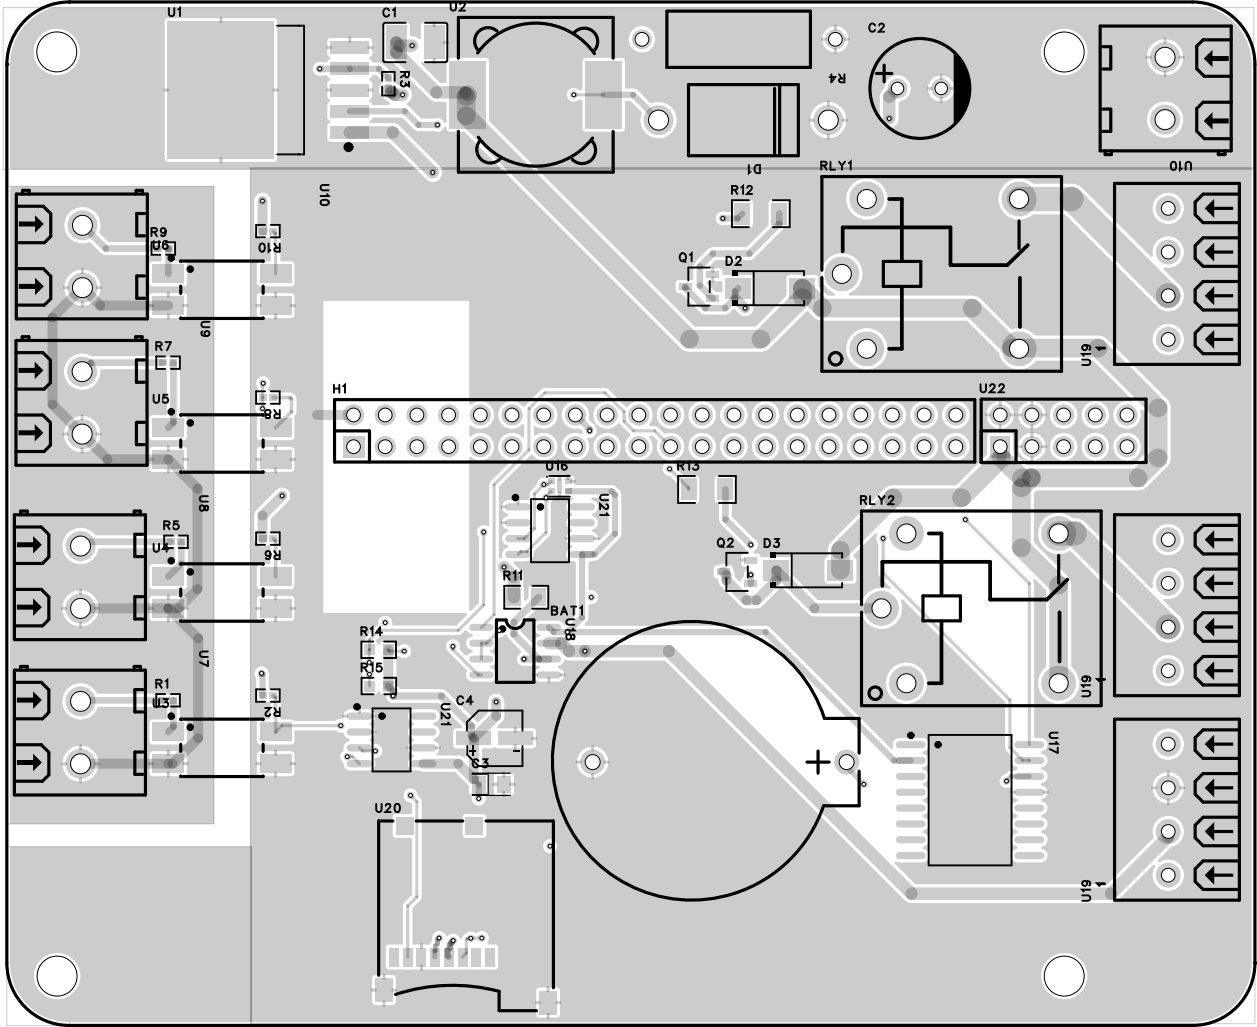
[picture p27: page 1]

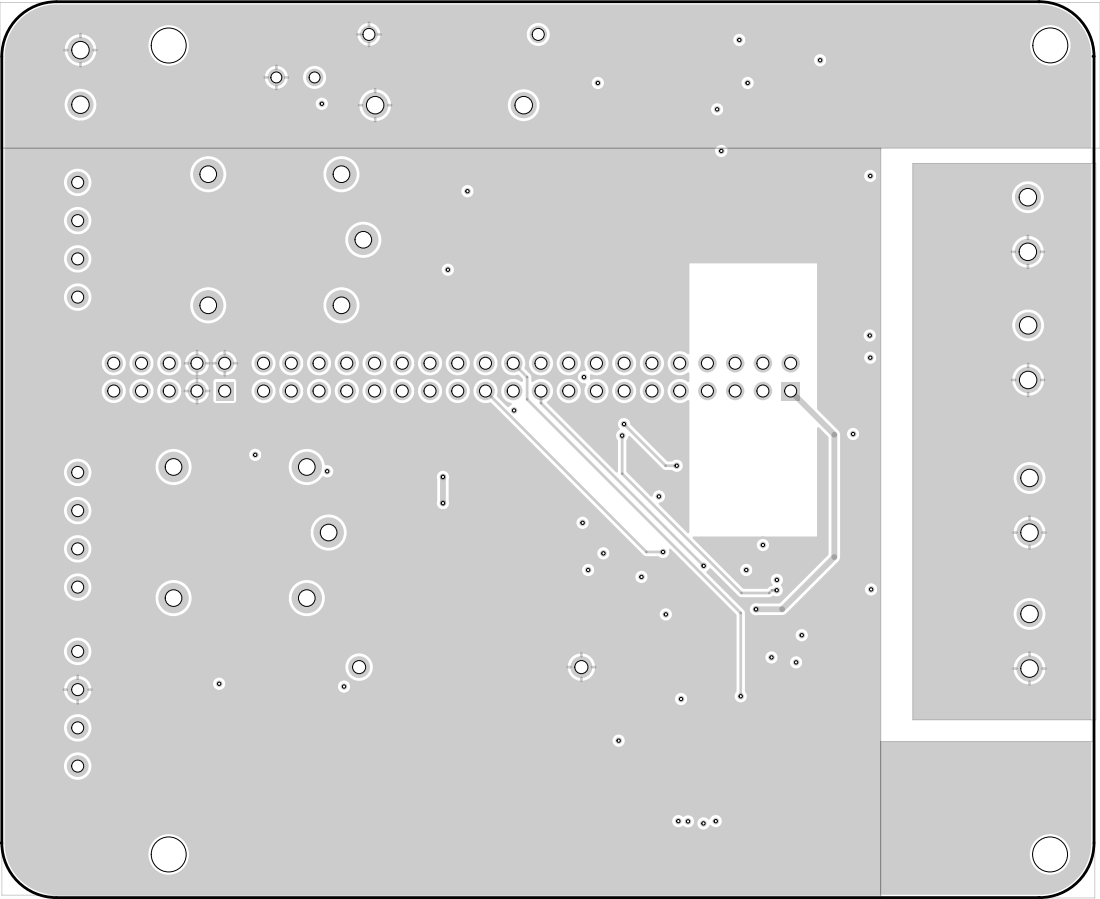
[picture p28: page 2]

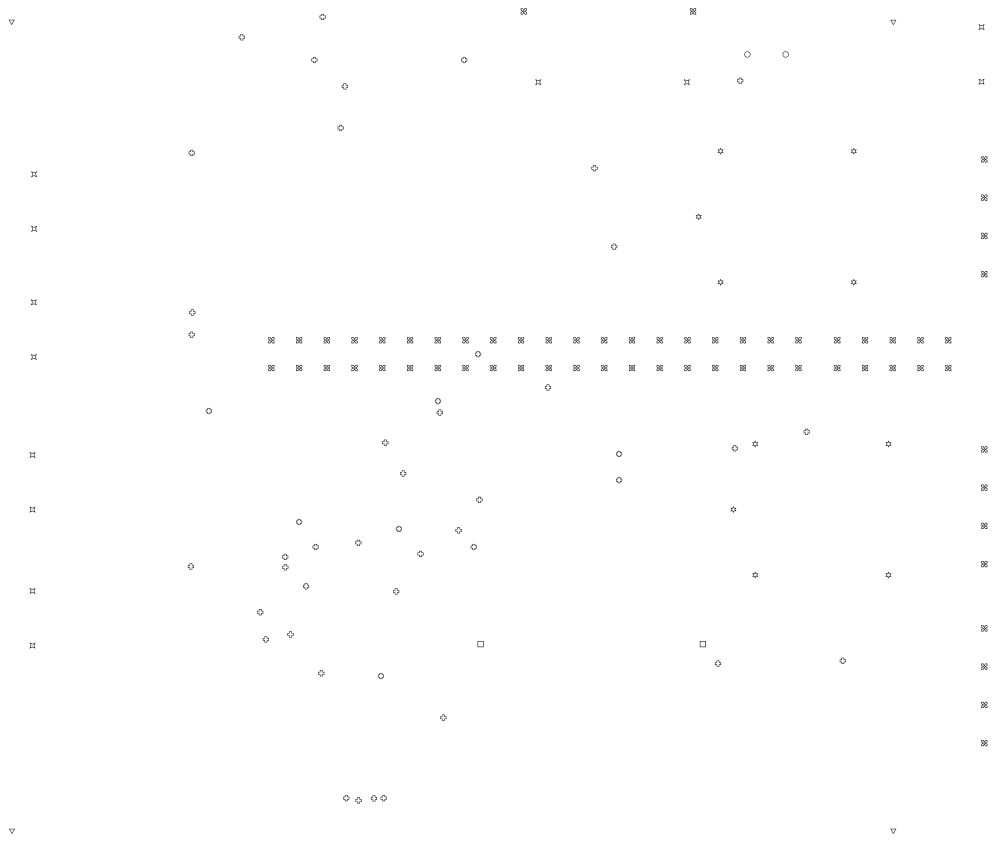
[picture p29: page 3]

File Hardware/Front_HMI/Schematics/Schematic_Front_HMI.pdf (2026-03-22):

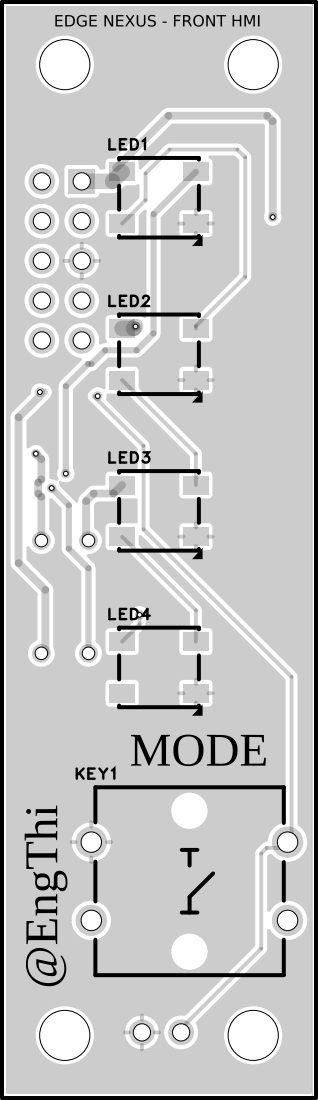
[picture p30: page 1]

EDGE NEXUS - FRONT HMI

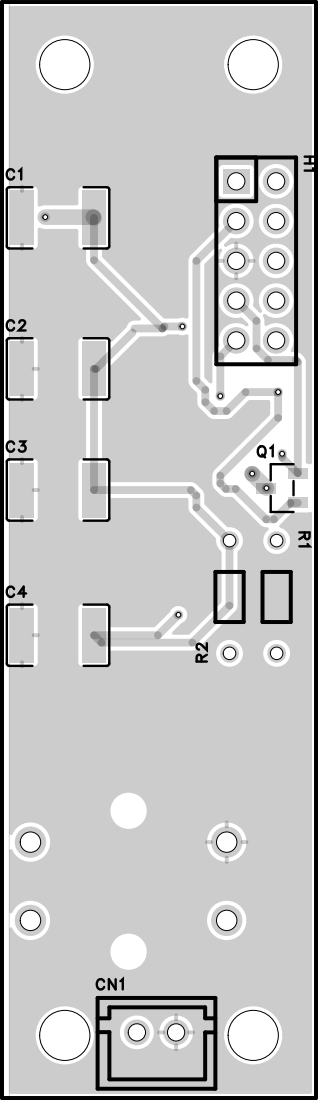
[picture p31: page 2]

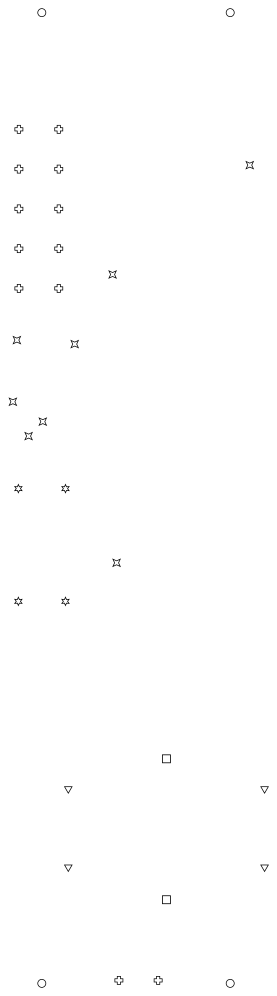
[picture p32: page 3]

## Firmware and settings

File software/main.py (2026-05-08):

# Edge Nexus V2 - ESP32-S3 Standalone Industrial Controller
# MicroPython bring-up firmware
# Author: @EngThi
#
# Pinout (WeAct Studio ESP32-S3):
#   SDA  -> GPIO 8
#   SCL  -> GPIO 9
#   SD CS -> GPIO 10
#   RS485 DE/RE -> GPIO 4
#   RS485 TX -> GPIO 5
#   RS485 RX -> GPIO 6
#   RELAY_1 -> GPIO 11
#   RELAY_2 -> GPIO 12
#   ISO_IN_1..4 -> GPIO 14, 15, 16, 17

import os
import time
from machine import Pin, SDCard, SoftI2C, UART


I2C_SDA = 8
I2C_SCL = 9
SD_CS = 10

RS485_DE = 4
RS485_TX = 5
RS485_RX = 6

RELAY_1 = 11
RELAY_2 = 12
ISO_INPUT_PINS = (14, 15, 16, 17)

SHT41_ADDR = 0x44
INA219_ADDRS = (0x40, 0x41)
DS3231_ADDR = 0x68


i2c = SoftI2C(scl=Pin(I2C_SCL), sda=Pin(I2C_SDA), freq=400_000)

relay1 = Pin(RELAY_1, Pin.OUT, value=0)
relay2 = Pin(RELAY_2, Pin.OUT, value=0)

rs485_de = Pin(RS485_DE, Pin.OUT, value=0)
uart = UART(1, baudrate=9600, tx=RS485_TX, rx=RS485_RX)

iso_inputs = [Pin(pin, Pin.IN, Pin.PULL_UP) for pin in ISO_INPUT_PINS]


def bcd_to_dec(value):
    return ((value >> 4) * 10) + (value & 0x0F)


def i2c_scan():
    try:
        return i2c.scan()
    except Exception:
        return []


def sht41_read():
    """Return (temperature_C, humidity_pct), or (None, None) on error."""
    try:
        i2c.writeto(SHT41_ADDR, bytes([0xFD]))
        time.sleep_ms(10)
        raw = i2c.readfrom(SHT41_ADDR, 6)
        t_raw = (raw[0] << 8) | raw[1]
        h_raw = (raw[3] << 8) | raw[4]
        temp = -45 + 175 * t_raw / 65535
        hum = -6 + 125 * h_raw / 65535
        return round(temp, 2), round(max(0, min(100, hum)), 2)
    except Exception:
        return None, None


def ina219_read_voltage(addr):
    """Return bus voltage in volts, or None on error."""
    try:
        i2c.writeto(addr, bytes([0x02]))
        time.sleep_ms(2)
        raw = i2c.readfrom(addr, 2)
        v_raw = ((raw[0] << 8) | raw[1]) >> 3
        return round(v_raw * 0.004, 3)
    except Exception:
        return None


def ds3231_read_time():
    """Return a compact timestamp from DS3231, or uptime fallback."""
    try:
        i2c.writeto(DS3231_ADDR, bytes([0x00]))
        raw = i2c.readfrom(DS3231_ADDR, 7)
        sec = bcd_to_dec(raw[0] & 0x7F)
        minute = bcd_to_dec(raw[1])
        hour = bcd_to_dec(raw[2] & 0x3F)
        day = bcd_to_dec(raw[4])
        month = bcd_to_dec(raw[5] & 0x1F)
        year = 2000 + bcd_to_dec(raw[6])
        return f"{year:04d}-{month:02d}-{day:02d} {hour:02d}:{minute:02d}:{sec:02d}"
    except Exception:
        return f"uptime_ms={time.ticks_ms()}"


def mount_sd():
    try:
        sd = SDCard(slot=2, cs=Pin(SD_CS))
        os.mount(sd, "/sd")
        return True
    except Exception:
        return False


def append_log(line):
    try:
        with open("/sd/edge_nexus.csv", "a") as log:
            log.write(line + "\n")
    except Exception:
        pass


def rs485_send(data):
    rs485_de.value(1)
    time.sleep_ms(1)
    uart.write(data)
    time.sleep_ms(4)
    rs485_de.value(0)


def build_telemetry():
    temp, hum = sht41_read()
    voltages = [ina219_read_voltage(addr) for addr in INA219_ADDRS]
    iso_state = [pin.value() for pin in iso_inputs]
    timestamp = ds3231_read_time()

    # Inputs are active-low after the optocoupler stage.
    relay1.value(1 if iso_state[0] == 0 else 0)
    relay2.value(1 if iso_state[1] == 0 else 0)

    return {
        "timestamp": timestamp,
        "temp": temp,
        "hum": hum,
        "v0": voltages[0],
        "v1": voltages[1],
        "iso": iso_state,
        "relay1": relay1.value(),
        "relay2": relay2.value(),
    }


def telemetry_line(data):
    iso_bits = "".join(str(value) for value in data["iso"])
    return (
        f"EN2,{data['timestamp']},"
        f"T={data['temp']},H={data['hum']},"
        f"V0={data['v0']},V1={data['v1']},"
        f"ISO={iso_bits},R1={data['relay1']},R2={data['relay2']}"
    )


print("Edge Nexus V2 - booting...")
print("I2C devices:", [hex(addr) for addr in i2c_scan()])

sd_ready = mount_sd()
print("MicroSD logging:", "enabled" if sd_ready else "not mounted")

if sd_ready:
    append_log("timestamp,temp,hum,v0,v1,iso,relay1,relay2")

while True:
    telemetry = build_telemetry()
    line = telemetry_line(telemetry)

    print(line)
    rs485_send((line + "\r\n").encode())

    if sd_ready:
        append_log(
            f"{telemetry['timestamp']},{telemetry['temp']},{telemetry['hum']},"
            f"{telemetry['v0']},{telemetry['v1']},"
            f"{''.join(str(value) for value in telemetry['iso'])},"
            f"{telemetry['relay1']},{telemetry['relay2']}"
        )

    time.sleep(5)

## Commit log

2026-03-06 docs: updating JOURNAL - Completed the enclousure CAD
2026-03-18 feat: Organize project structure and update documentation
    [3D_HMI_2026-03-18.step, 3D_PCB_Shield_2026-03-18.step, BOM_HMI_2026-03-18.csv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]
2026-03-22 docs: Add complete project BOM with NVIDIA Jetson Orin Nano
    [BOM.csv]
2026-03-22 docs: Update README with project structure including main BOM
2026-03-22 chore: Final project audit, organization and documentation polish
    [BOM_HMI_2026-03-18.csv, BOM_PCB_Shield_2026-03-18.csv, Case.stl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]
2026-03-22 docs: Final project polish, professional schematics organization and CAD link
    [BOM.csv]
2026-03-22 docs: Final professional renaming of all project files and assets
    [Edge_Nexus_Enclosure_Case.stl, Edge_Nexus_HMI_3D_Model.step, Edge_Nexus_HMI_BOM.csv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]
2026-03-23 docs: Correct BOM total to 70.02 based on cart images
2026-03-28 docs: Update ESP32-S3 price to $6.66 and add direct AliExpress link
    [BOM.csv]
2026-03-29 feat: Complete Edge Nexus V2 documentation and asset update
    [Edge_Nexus_Isolation_Shield_3D_Model.step, Edge_Nexus_Isolation_Shield_BOM.csv, Edge_Nexus_Isolation_Shield_PickAndPlace.csv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]
2026-03-30 feat: Final professional audit and documentation for Edge Nexus V2
    [BOM.csv]
2026-03-30 fix: replace AHT20 with correct SHT41 sensor in journal
2026-03-30 fix: remove duplicate BOM section, fix SHT41 naming, replace jetson stub with ESP32 firmware, fix journal typos
    [main.py]
2026-03-30 docs: add reviewer note, assembly strategy, and shipping evidence section
2026-03-30 chore: remove legacy jetson status script
2026-03-30 docs: sync complete BOM to fabrication folder and cleanup empty directories
    [Edge_Nexus_Main_Shield_BOM.csv]
2026-04-01 Fix NVIDIA board cost and format in JOURNAL.md
    Updated the cost of the NVIDIA board and made minor formatting adjustments.
2026-04-14 Add images of the HMI PCB
2026-05-08 docs: align Edge Nexus budget and journal
    [BOM.csv, Edge_Nexus_Main_Shield_BOM.csv]
2026-05-08 docs: finalize Edge Nexus cart pricing
    [BOM.csv, Edge_Nexus_Main_Shield_BOM.csv, Edge_Nexus_Main_Shield_PickAndPlace.csv]
2026-05-08 docs: include Front HMI parts in BOM
    [BOM.csv]
2026-05-08 docs: fix Edge Nexus HMI cart budget
    [BOM.csv]
2026-06-06 docs: finalize hardware budget v2 and organize new assets
    [BOM.csv, Edge_Nexus_HMI_BOM_Detailed.csv]
2026-06-07 docs: Update budget, BOM, assets and OnShape link for Edge-Nexus V2
    [BOM.csv, BOM_LCSC_HMI_Update.csv, BOM_LCSC_New.csv]
2026-06-07 Fix BOM details for Front HMI in README
    Updated README to include Front HMI BOM and cart changes.
2026-06-07 fix: remove comment lines from BOM.csv so GitHub renders it correctly
    [BOM.csv]
